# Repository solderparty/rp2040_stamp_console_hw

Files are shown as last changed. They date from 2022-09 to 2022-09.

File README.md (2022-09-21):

# RP2040 Stamp Handheld Console (Flux Project)

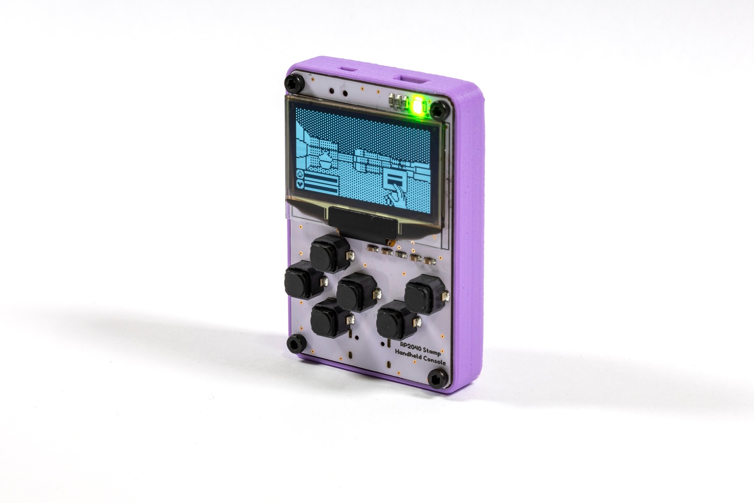
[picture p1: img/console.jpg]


This Flux project transforms an RP2040 Stamp into a small handheld console with a **1.3" 128x64 OLED**, D-pad + A and B buttons, **RGB LED**, a **Qwiic** connector, a power switch, and a **speaker**.

As the console is powered by the Stamp, you can run **CircuitPython** on it, as well as **Arduino**, including experimental support for the **Arduboy2** library.

# Details

To make it truly portable, you will need a battery. This product does not ship with one, you can use any 3.7V/4.2V LiPo that is around or smaller than 40x30 mm. We recommend the [500mAh LiPo from Pimoroni](https://shop.pimoroni.com/products/lipo-battery-pack?variant=20429082055).

You can find a 3D-printable model for the case on [Printables](https://www.printables.com/model/279210-rp2040-stamp-handheld-console-case). You will also need four M2x4 screws and four M2 threaded inserts. 

# What does "Flux Project" mean?

At Solder Party, we always want to get interesting products in people's hands. However, releasing a product is no easy feat, we need to make sure everything is polished, provide documentation, examples, and extensive support.

With Flux, we want to streamline the process a bit, get fun projects into everyone's hands quicker.

Flux projects are more experimental in nature. While they are tested and verified, the documentation might not be fully there, and the examples might be very basic. 
Flux projects are targeted at people who are not scared to put a bit of extra work into getting the project to where they want it to end up.
These projects are also produced in smaller quantities, there is no guarantee there will be more produced in the future. Even if there is a new batch, it might differ from the initial version. 

These projects are in constant Flux, so to speak.

If there is enough interest, a Flux project might become a fully-fledged Solder Party product in the future, but there is no guarantee.

# Links

For more information visit https://flux.solder.party/

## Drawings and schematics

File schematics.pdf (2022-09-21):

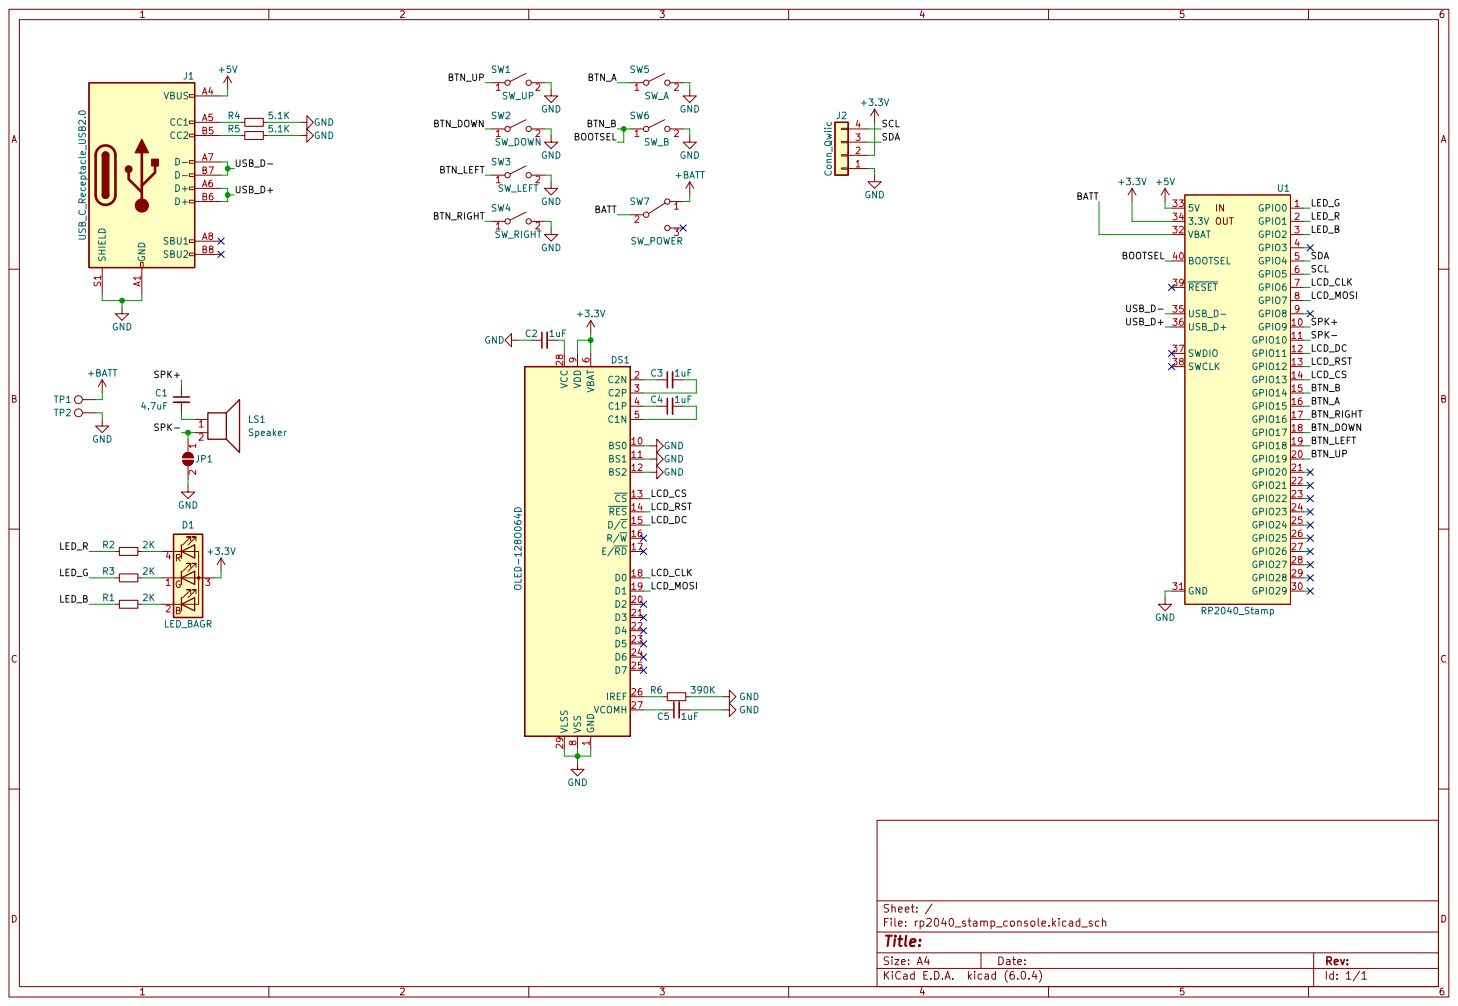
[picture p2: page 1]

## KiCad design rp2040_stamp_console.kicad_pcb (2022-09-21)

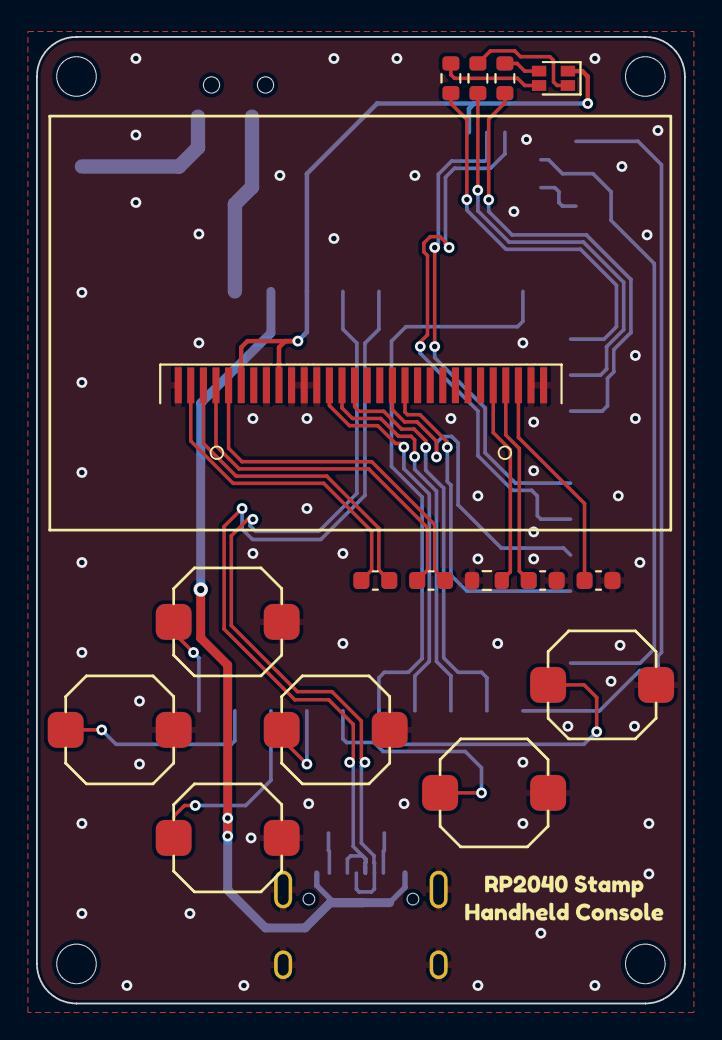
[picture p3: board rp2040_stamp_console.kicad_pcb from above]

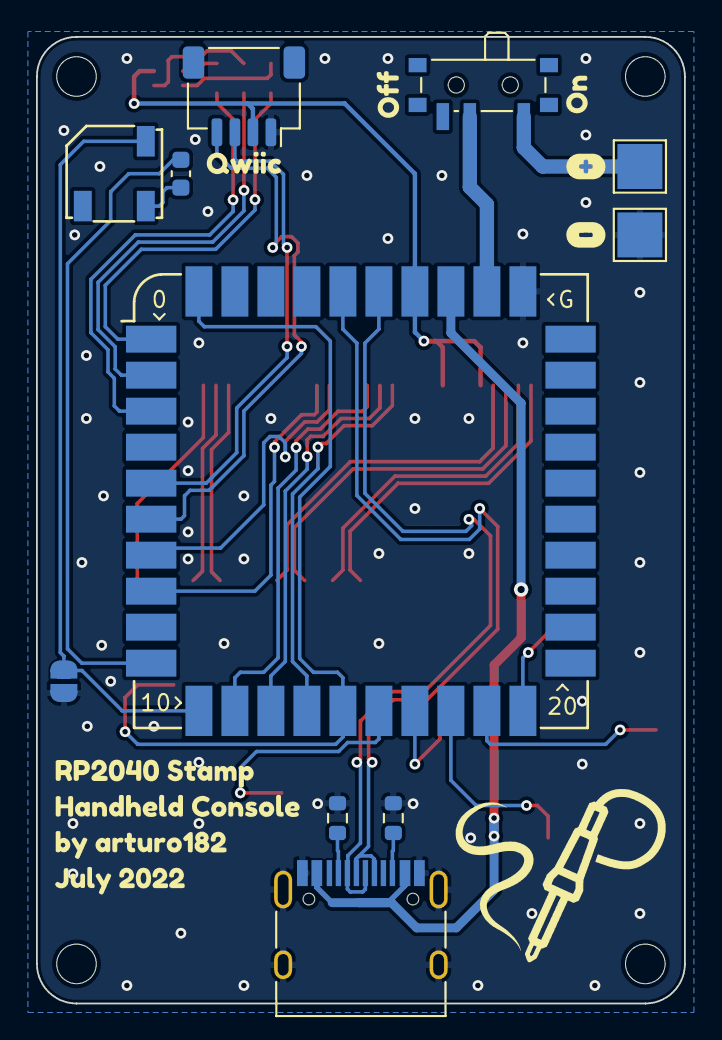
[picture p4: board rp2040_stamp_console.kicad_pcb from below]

Board: 2 copper layers, 36.0 x 53.7 mm, 35 parts (17 on the bottom side), 38 nets.

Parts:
C1: 4.7uF; C_0603_1608Metric
C2, C3, C4, C5: 1uF; C_0603_1608Metric
D1: LED_BAGR; LED_RGBA_0606
DS1: OLED-128O064D
J1: USB_C_Receptacle_USB2.0; USB_C_Receptacle_HRO_TYPE-C-31-M-12
J2: Conn_Qwiic; JST_SH_SM04B-SRSS-TB_1x04-1MP_P1.00mm_Horizontal
JP1: SJ_LOUDER; SolderJumper-2_P1.3mm_Open_RoundedPad1.0x1.5mm
LS1: Speaker; CMT-5023S
R1, R2, R3: 2K; R_0603_1608Metric
R4, R5: 5.1K; R_0603_1608Metric
R6: 390K; R_0603_1608Metric
SW1: SW_UP; RMT-CZ66
SW2: SW_DOWN; RMT-CZ66
SW3: SW_LEFT; RMT-CZ66
SW4: SW_RIGHT; RMT-CZ66
SW5: SW_A; RMT-CZ66
SW6: SW_B; RMT-CZ66
SW7: SW_POWER; SW_SPDT_PCM12
TP1: TP_BATT+; TestPoint_Pad_2.5x2.5mm
TP2: TP_BATT-; TestPoint_Pad_2.5x2.5mm
U1: RP2040_Stamp; RP2040_Stamp_SMD
kibuzzard-62C6F28A: G***; kibuzzard-62C6F28A
kibuzzard-62C56D6F, kibuzzard-62C56D6F#2: G***; kibuzzard-62C56D6F
kibuzzard-62C5723D: G***; kibuzzard-62C5723D
kibuzzard-62C57215: G***; kibuzzard-62C57215
kibuzzard-62DEDED4: G***; kibuzzard-62DEDED4
kibuzzard-62DEDF00: G***; kibuzzard-62DEDF00
kibuzzard-62DEDF0B: G***; kibuzzard-62DEDF0B

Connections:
+3.3V: D1.3 (A), DS1.6 (VBAT), DS1.9 (VDD), J2.2, U1.34 (3.3V)
+5V: J1.A4 (VBUS), J1.A9 (VBUS), J1.B4 (VBUS), J1.B9 (VBUS), U1.33 (5V)
+BATT: SW7.1 (A), TP1.1
/BATT: SW7.2 (B), U1.32 (VBAT)
/BOOTSEL: SW6.1 (A), U1.15 (GPIO14), U1.40 (BOOTSEL)
/BTN_A: SW5.1 (A), U1.16 (GPIO15)
/BTN_DOWN: SW2.1 (A), U1.18 (GPIO17)
/BTN_LEFT: SW3.1 (A), U1.19 (GPIO18)
/BTN_RIGHT: SW4.1 (A), U1.17 (GPIO16)
/BTN_UP: SW1.1 (A), U1.20 (GPIO19)
/LCD_CLK: DS1.18 (D0), U1.7 (GPIO6)
/LCD_CS: DS1.13 (~CS), U1.14 (GPIO13)
/LCD_DC: DS1.15 (D/~C), U1.12 (GPIO11)
/LCD_MOSI: DS1.19 (D1), U1.8 (GPIO7)
/LCD_RST: DS1.14 (~RES), U1.13 (GPIO12)
/LED_B: R1.1, U1.3 (GPIO2)
/LED_G: R3.1, U1.1 (GPIO0)
/LED_R: R2.1, U1.2 (GPIO1)
/SCL: J2.4, U1.6 (GPIO5)
/SDA: J2.3, U1.5 (GPIO4)
/SPK+: C1.1, U1.10 (GPIO9)
/SPK-: JP1.1 (A), LS1.2, U1.11 (GPIO10)
/USB_D+: J1.A6 (D+), J1.B6 (D+), U1.36 (USB_D+)
/USB_D-: J1.A7 (D-), J1.B7 (D-), U1.35 (USB_D-)
GND: C2.1, C5.2, DS1.1 (GND), DS1.8 (VSS), DS1.10 (BS0), DS1.11 (BS1), DS1.12 (BS2), DS1.29 (VLSS), DS1.30 (GND), J1.A1 (GND), J1.A12 (GND), J1.B1 (GND), J1.B12 (GND), J1.S1 (SHIELD), J2.1, JP1.2 (B), R4.2, R5.2, R6.2, SW1.2 (B), SW2.2 (B), SW3.2 (B), SW4.2 (B), SW5.2 (B), SW6.2 (B), TP2.1, U1.31 (GND)
unnamed: C1.2, LS1.1
unnamed: C2.2, DS1.28 (VCC)
unnamed: C3.1, DS1.2 (C2N)
unnamed: C3.2, DS1.3 (C2P)
unnamed: C4.1, DS1.4 (C1P)
unnamed: C4.2, DS1.5 (C1N)
unnamed: C5.1, DS1.27 (VCOMH)
unnamed: D1.1 (GK), R3.2
unnamed: D1.2 (BK), R1.2
unnamed: D1.4 (RK), R2.2
unnamed: DS1.26 (IREF), R6.1
unnamed: J1.A5 (CC1), R4.1
unnamed: J1.B5 (CC2), R5.1

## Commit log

2022-07-07 Rev 1
    [rp2040_stamp_console.kicad_pcb, rp2040_stamp_console.kicad_sch]
2022-09-21 Rev 2
    [rp2040_stamp_console.kicad_pcb, rp2040_stamp_console.kicad_sch]
